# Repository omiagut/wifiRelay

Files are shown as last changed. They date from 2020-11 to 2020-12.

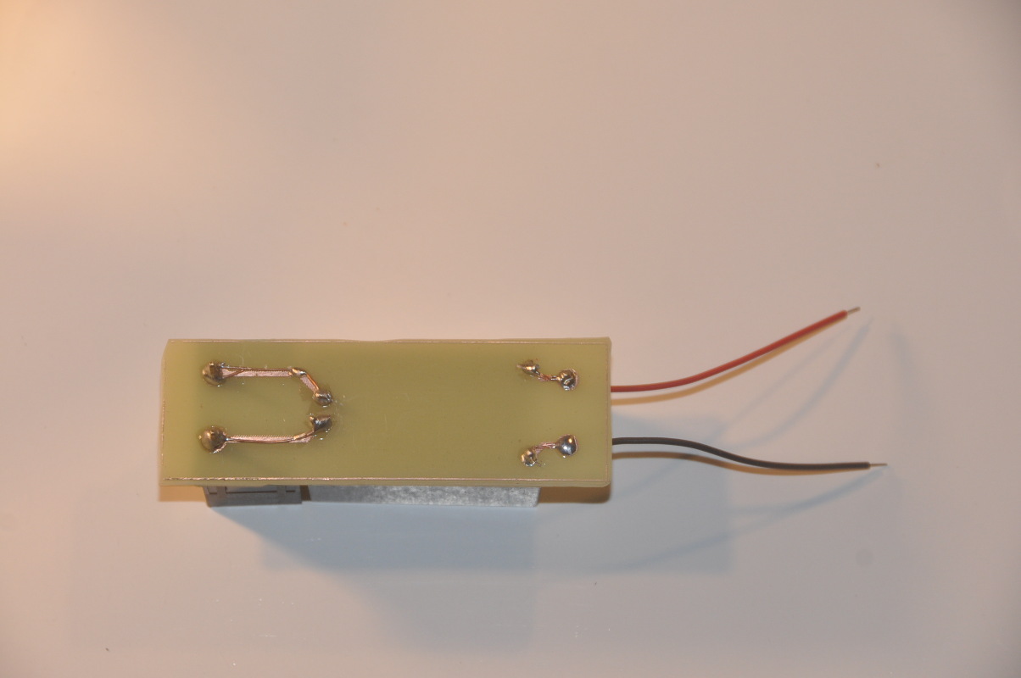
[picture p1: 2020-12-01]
pictures/p02.jpg

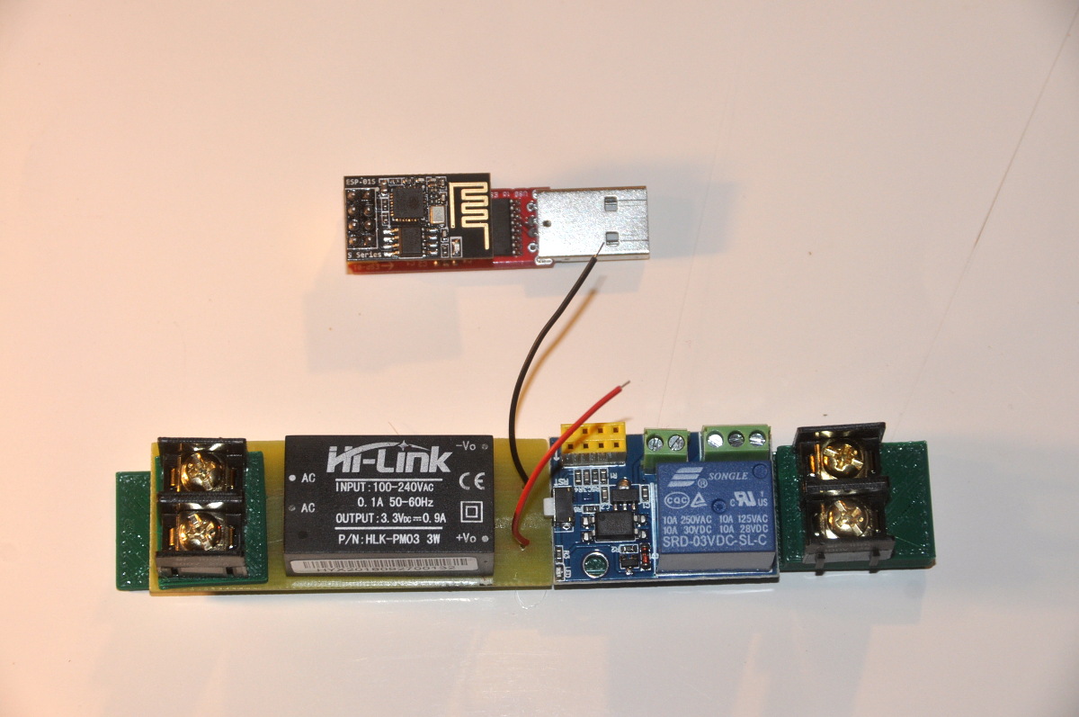
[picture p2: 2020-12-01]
pictures/p03.jpg

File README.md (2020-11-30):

wifiRelay
a way to create an electrical relay with a wifi command.
using IDE :
- Arduino (ino, h, cpp files)
- gedit (html files)
- freeCad (stl files)
- kicad (and gimp, to provide a .pdf file for printing the PCB)

wifiRealy.ino drives a relay from a web client, Firefox, Chrome, Midori and maybe Edge (I only use Linux Debian)
Before using wifiRelay.ino, ssid and password values must be written in the EEPROM memory by eepromPutEsp.ino.
Then C_Eprom class (c_eprom.h, c_eprom.cpp) reads those values for wifiRelay.ino, and handles user's changes.

webPage.html and boxPage.html are in the data directory, and uploaded in the SPIFFS memory.

eepromPutEsp.ino must provide values to connect as an Access Point (WIFI_AP mode)
 - ssid like "192.168.x.x", for example 192.168.4.10
 - password 8..31 bytes
With boxPage.html, the user may change these values. He can change his password, or change for a WIFI_STA mode connexion. The esp8266 becomes a station depending on his box.	In this case, the user must find by himself the address he has be given by his box with the command line 
user@user:~$ nmap -sP 192.168.1.* (if the box has 192.168.1.0 address) or 192.168.*.* (wil takes more time) or a corresponding command line with Mac Os or windows.

As EEPROM memory is situated at the end of SPIFFS memory, use the tool "flash size 1MB FS 64KB" to flash eepromPutEsp and wifiRelay.

wifiRelay setup
- 1 tries to connect in WIFI_AP mode with eepromPutEsp.ino ssid.
- 2 if it fails (the ssid is not the original one) , it tries to connect in WIFI_STA mode
- 3 if it fails, whatever the reason, C_Eprom takes the eepromPutEsp.ino values back and the esp8266 is connected as an Access Point.
With this method, you ensure a connexion, as closed as possible to what the user expects.

On and Off buttons in webPage.html allow to switch the relay on or off.

Thanks for your help, 
 * https://circuits4you.com/
 * https://github.com/esp8266/Arduino
 * https://projetsdiy.fr/e66-serveur-ftp-echange-fichiers-spiffs/
 * https://www.screenfeed.fr/blog/personnalisation-chesp82ckbox-boutons-radio-sans-image-0570/
 * http://tiptopboards.free.fr/arduino_forum/viewtopic.php?f=2&t=54

.stl files are written by freeCad, to create .gcode files for any 3D printer. (see the pictures)
You need :
2 connectors able to support AC 220V
1 HKL-PM01 
1 ESP8266-01 relay (5V DC)
1 male and 1 female electrical outlet
3 feet of electrical wire
Connexions are easier with a small PCB, and still easier to wire if you stick the parts on plaque.stl and rehausse.stl
The red wires are connected to the relay, one to com, one to nc (neutral close) because of digitalWrtite(GPIO, HIGH)

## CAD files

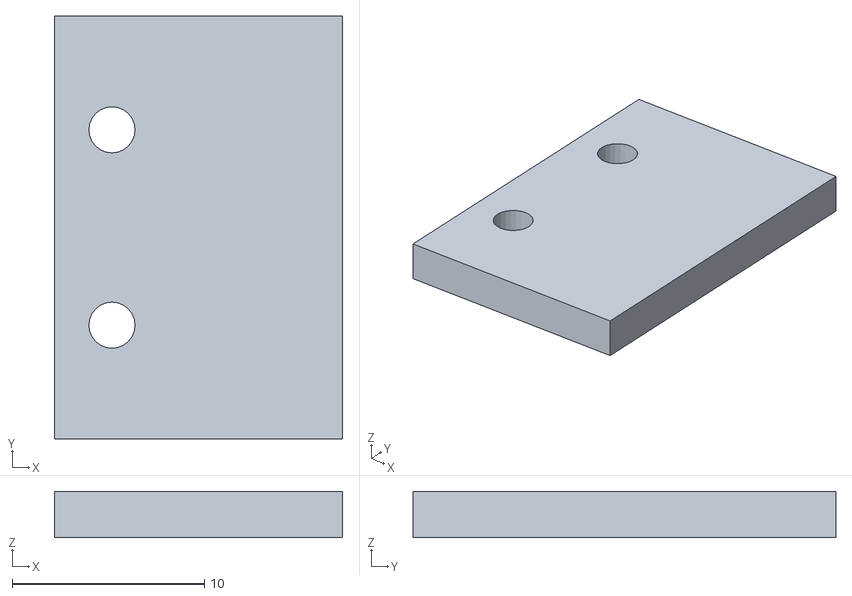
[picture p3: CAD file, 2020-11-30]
stl/rehausse.stl
15.0 x 22.0 x 2.40

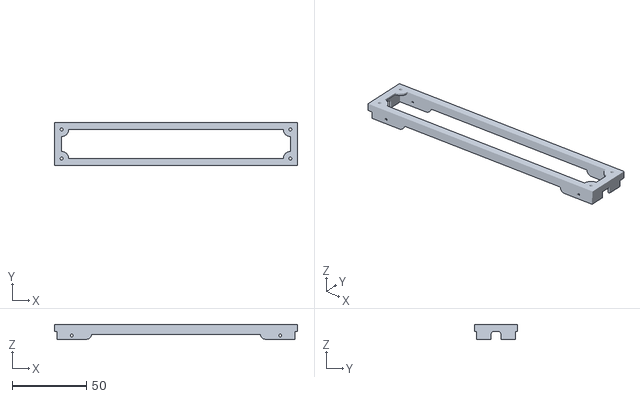
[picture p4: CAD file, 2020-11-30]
stl/boiteEntretoise.stl
163.2 x 29.2 x 9.80

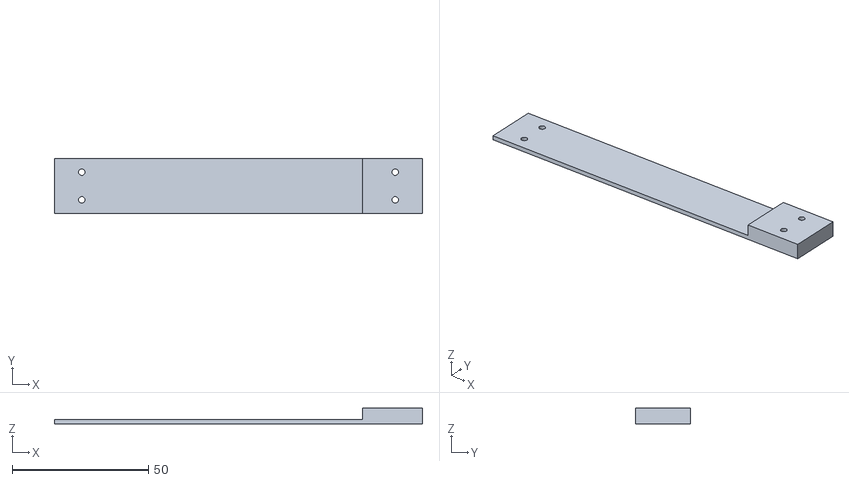
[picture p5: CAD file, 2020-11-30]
stl/plaque.stl
135.0 x 20.0 x 5.80

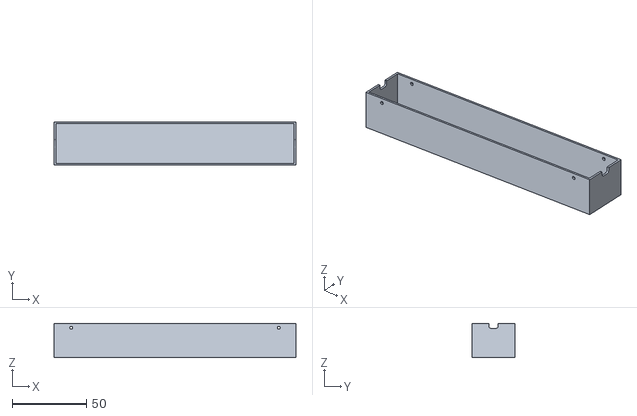
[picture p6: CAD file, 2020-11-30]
stl/boiteFond.stl
163.2 x 29.2 x 23.2

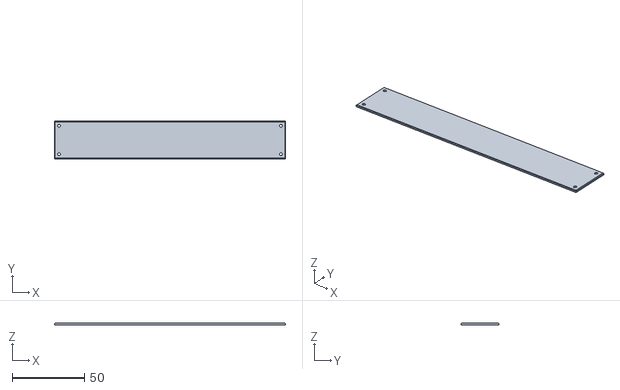
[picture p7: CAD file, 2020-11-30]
stl/boiteCouvercle.stl
160.0 x 26.0 x 1.20

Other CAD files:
stl/ci-pla01.FCStd

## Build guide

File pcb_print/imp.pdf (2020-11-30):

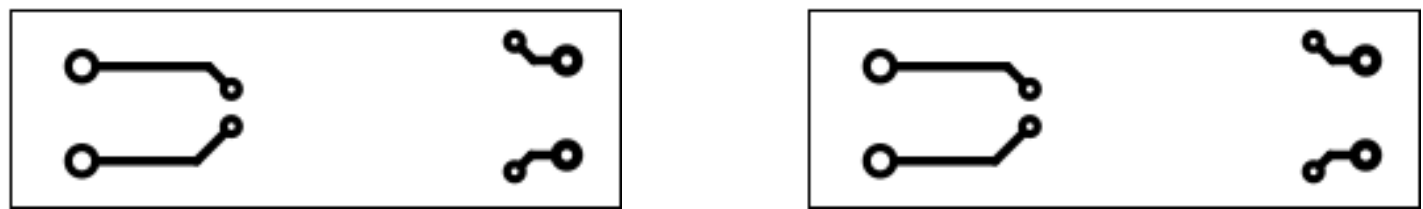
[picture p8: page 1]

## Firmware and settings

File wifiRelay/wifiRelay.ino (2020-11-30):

/* -----------------------------------------------------------------------------------------
 * wifiRelay.ino commande un relais à partir d'une interface graphique 
 * accessible dans un navigateur web : Firefox, Chrome, Midori, Edge
 * les valeurs ssid et password doivent être pré-écrites en EEPROM avec eepromPutEsp.ino  
 * La classe C_Eprom se charge de gérer ces valeurs si l'utilisateur les change
 * et les fournit à wifiRelay.ino pour connection.
 * 
 * Les pages wepPage.html et boxPage.html du serveur sont mémorisées en SPIFFS
 * 
 * eepromPutEsp doit fournir des valeurs permettant de se connecter en mode Access Point (WIFI_AP)
 * L'utilisateur peut choisir de changer ces valeurs, afin de se connecter en Mode station (WIFI_STA)
 * s'il dispose d'une box
 * Dans ce cas, l'utilisateur doit trouver lui-même, avec la commande 
 * nmap -sP 192.168.1.* (par exemple) quelle adresse sa box lui a attribué.
 * 
 * wifiRelay.ino, à l'initialisation, 
 * - tente de se connecter en mode WIFI_AP avec les coordonnées fournies par eepromPutEsp, via C_Eprom
 * - en cas d'échec, tente 20 fois maximum de se connecter en mode WIFI_STA avec les coordonnées 
 *    que l'utilisateur a validées dans la page boxPage.html
 * - en cas d'échec, quelle qu'en soit la raison, C_Eprom remet identifiant en mot de passe à    
 *    leurs valeurs d'origine, et se connecte en mode WIFI_AP
 * Cette méthode garantit une connection, et la plus attendue par l'utilisateur.
 * 
 * Les boutons On et Off de la page webPage.html permettent d'ouvrir ou fermer le relais.
 * 
 * Merci pour votre aide ,
 * https://circuits4you.com/
 * https://github.com/esp8266/Arduino
 * https://projetsdiy.fr/e66-serveur-ftp-echange-fichiers-spiffs/
 * https://www.screenfeed.fr/blog/personnalisation-chesp82ckbox-boutons-radio-sans-image-0570/
 * http://tiptopboards.free.fr/arduino_forum/viewtopic.php?f=2&t=54
 * ------------------------------------------------------------------------------------------
*/
#include <ESP8266WiFi.h>
#include <ESP8266WebServer.h>
#include <ESP8266mDNS.h>
#include <FS.h>
#include "c_eprom.h"
#define GPIO 0 // commande du relais GPIO0 

// identifiant et Mot de passe
C_Eprom c_eprom;
String boxSsid = "";
String boxPass = "";

ESP8266WebServer server(80);
String webPage;
String boxPage;

/* @@ssid@@ est la valeur originelle de la variable ssid, dans la section javascript de boxPage.html
 * cette valeur est changée en c_eprom.ssid() dans la fonction updateBoxPage() de wifiRelay.ino
 * elle s'affiche dans le champ ssid de la page boxPage.html
*/
String ssidHtml = "@@ssid@@"; 

void setup() {
  Serial.begin(9600);
  while (!Serial) {;}
  SPIFFS.begin();
  wait(500);

  pinMode(GPIO, OUTPUT);
  digitalWrite(GPIO, HIGH);

  // charge l'identifiant et le mot de passe depuis l' EEPROM
  boxSsid = c_eprom.ssid();
  boxPass = c_eprom.pass();
 
  // se connecte en Accès Point, sinon essaie en mode Station
  // si les paramètres de connection à la box sont invalides
  // (mauvaise saisie, box changée ou arrêtée, ..)
  // retour à la configuration d'origine, et nouvelle tentative en Point d'accés
  if (!toAp()) {
    if (!toBox()) {
      c_eprom.toOrigine();
      boxSsid = c_eprom.ssid();
      boxPass = c_eprom.pass();
      toAp();
    }
  }

  if (MDNS.begin("wifiRelay")) {
    Serial.println("MDNS responder started");
  }

  server.on("/", handleRoot);
  server.on("/switch", handleSwitch); // On, Off
  server.on("/box", handleBox);       // positionne sur boxPage
  server.on("/check", handleCheck);   // gère les changements utilisateur de ssid et de password

  server.begin();
  Serial.println("your server is working");

  webPage = createFromData("/webPage.html");
  boxPage = createFromData("/boxPage.html");
}

// Equivalent delay avec yield
void wait(const int x) {
  int timer = millis();
  while (millis() - timer < x) {
    yield();
  }
}

// tente de créer un Point d'Accés, si l'identificateur est
// toujours celui installé par eepromPutEsp
bool toAp() {
  if (boxSsid != c_eprom.orig())
    return false;

  IPAddress IP = c_eprom.setIP();
  IPAddress subnet(255, 255, 255, 0);
  WiFi.mode(WIFI_AP);
  WiFi.softAPConfig(IP, IP, subnet);
  WiFi.softAP(boxSsid.c_str(), boxPass.c_str()); 
  return true;
}

// connexion à la box
// attention : l'adresse du serveur n'est plus 192.168.4.17,
// mais celle choisie par votre box, accessible pour les linuxiens
// par la commande user@user:~$ nmap -sP 192.168.1.* (si vos adresses privées sont 192.168.1.x)
bool toBox() {
  int counter = 0;
  bool isOk = false;

  WiFi.mode(WIFI_STA);
  WiFi.begin(boxSsid.c_str(), boxPass.c_str());

  // 20 essais de connection
  while (counter < 20 && WiFi.status() != WL_CONNECTED) {
    Serial.print(".");
    counter++;
    wait(500);
  }
  Serial.println("");
  if (WiFi.status() == WL_CONNECTED) {
    Serial.print("IP address: ");
    Serial.println(WiFi.localIP());
    isOk = true;
  }
  return isOk;
}

// charge un fichier .html de la SPIFFS
// dans une chaîne de caractères
String createFromData(String qHtml) {
  String str = "";
  File dataFile = SPIFFS.open(qHtml, "r");
  for (int i = 0; i < dataFile.size(); i++)
  {
    str += (char)dataFile.read();
  }
  dataFile.close();
  return str;
}

// remplace la variable ssid de boxPage.html dans la section javascript par sa valeur = eprom.m_ssid
// cette valeur est mémorisée dans ssidHtml, en cas de son changement ultérieur
void updateBoxPage() {
  if (ssidHtml != c_eprom.ssid()) { 
    boxPage.replace(ssidHtml, c_eprom.ssid());
    ssidHtml = c_eprom.ssid();
  }    
}

// connexion à la racine
void handleRoot() {
  server.send(200, "text/html", webPage);
}

// appui sur un bouton de la form "/switch"
// du fichier webPage.html
// server.arg prend la valeur de l'attribut name comme paramètre, 
// et renvoie une chaîne contenant la valeur de l'attribut value
// Ici, il faut 2 boutons ayant name="button", 1 avec value="On", 1 avec value="Off" (case sensitive)
void handleSwitch() {
  String s = server.arg("button");
  if (s == "On") {
    digitalWrite(GPIO, HIGH);
  }
  if (s == "Off") {
    digitalWrite(GPIO, LOW);
  }
  server.sendHeader("Location", "/");
  server.send(302, "text/html", "");
}

// appui sur le bouton "Box" de la form "box"
// du fichier webPage.html
void handleBox() {
  updateBoxPage(); // pour afficher la valeur c_eprom.ssid() dans le champ Ssid de boxPage.html
  server.send(302, "text/html", boxPage);
}

// appui sur le bouton "valider" de la form "check" du fichier boxPage.html
// Le fichier boxPage.html se charge de valider la saisie (javascript)
// mais ne peut contrôler la panne de box, le changement de box, l'erreur de saisie de password ...
// Après saisie, il faut réinitialiser l'esp8266-01 pour rendre les modifications opérationnelles
void handleCheck() {
  String s = server.arg("button");
  if (s == "Valider") {
    String strSsid = server.arg("ssid");
    String strPass = server.arg("pass");
    c_eprom.writeAll(strSsid, strPass); // Mémorisation dans l'eeprom
  }
  server.sendHeader("Location", "/");
  server.send(302, "text/html", "");
}

void loop() {
  server.handleClient();
}

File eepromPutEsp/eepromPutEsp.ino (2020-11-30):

/*
 * Initialisation de l'identifiant et du mot de passe pour wifiRelay
*/
#include <EEPROM.h>

#define idAddr 	0x00 // 4 octets pour la longueur de l'id, le reste pour l'id => 4 + maxi 64 < 80
#define pwAddr 	0x50 // 4 octets pour la longueur du pass, le reste pour le pass => 4 + maxi 64 < 80
#define oiAddr  0xA0 // la longueur maxi de l'id d'origine est celle de XXX.XXX.XXX.XXX + 4 => 19 < 32
#define opAddr  0xC0 // mot de passe d'origine conservé, longueur => 8

String id = "192.168.4.17";
String pw = "12345678";

int l; 

void writeId_Pw(int addr, String s) {
  EEPROM.put(addr, s.length());
  Serial.printf("%d %s", s.length()," - ");
  for (int i = 0; i < s.length(); ++i) {
    char c = (char) s.charAt(i);
    if (i < 64) { // 64 = longueur max identifiant ou pass
      EEPROM.write(addr+i+4, c);
      Serial.printf("%c, %s", c," ");
    }
  }
  Serial.println("");
}

void readId_Pw(int addr) {
  EEPROM.get(addr, l);
  Serial.printf("%d %s", l, " - ");
   for (int i = 0; i < l; ++i) {
    char c = EEPROM.read(addr+i+4);
    Serial.print(c);
  }
  Serial.println("");
}

void setup() {
  delay(10000);
  Serial.begin(9600);
  while (!Serial) {;}
  EEPROM.begin(512);
  writeId_Pw(idAddr, id);		// identifiant
  writeId_Pw(pwAddr, pw);		// password
  writeId_Pw(oiAddr, id);   // conserve l'id d'origine, le même que l'identifiant au départ
  writeId_Pw(opAddr, pw); 	// conserve le mot de passe d'origine, ibid
  EEPROM.commit();
}

void loop() { // seulement pour contrôler que l'écriture en eprom est bien faite
  delay(2000);
  Serial.println("read");
  readId_Pw(idAddr);
  readId_Pw(pwAddr);
  readId_Pw(oiAddr);
  readId_Pw(opAddr);
}

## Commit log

2020-11-27 Suppression de Readme.txt
2020-11-27 Create README.md
    Ajout de README.md directement sur github
2020-11-30 Ajout de wifiRealy/
2020-11-30 Ajout des fichiers stl
    [boiteCouvercle.stl, boiteEntretoise.stl, boiteFond.stl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]
2020-11-30 Ajout pcb_print/
2020-12-01 Ajout des fichiers non suivis
